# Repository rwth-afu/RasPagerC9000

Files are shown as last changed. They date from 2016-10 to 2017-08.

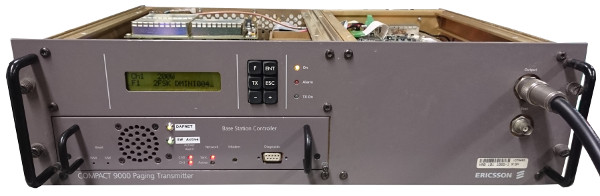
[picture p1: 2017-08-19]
software/website/frontansicht_klein.jpg

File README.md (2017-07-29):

# RasPagerC9000
Adapted Version of RasPager to generate Signals for Ericsson C9000 Paging Transmitter

Authors:
* Ralf Wilke DH3WR, Aachen
* Michael Delissen, Aachen
* Marvin Menzerath, Aachen
* Christian Jansen, Aachen
* Philipp Thiel, Aachen
* Thomas Gatzweiler

This software is released free of charge under the Creative Commons License of type "by-nc-sa". No commercial use is allowed. The software licenses of the used libs apply in any case.

Please notice that there is a new software development without the need of java and with web frontend. Check out https://github.com/rwth-afu/UniPager

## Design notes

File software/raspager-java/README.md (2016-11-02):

# RasPagerC9000: Java

## Run
* Install [Wiring Pi](http://wiringpi.com/download-and-install/)
* Create a configfile (using the example below)
* Run `root@raspberrypi:~# java -jar RasPagerC9000.jar -configfile=config.txt`

### Use Serial Port
You may need to prepeare the serial port interface first. There are two options available:

#### Simple
1. Use `raspi-config` to disable the console on the serial port.
2. Set `enable_uart=1` in `/boot/config.txt`
3. Reboot.

#### Advanced
1. Remove the `console=ttyAMA0,115200` and `kgdboc=ttyAMA0,115200` configuration parameters from the `/boot/cmdline.txt` configuration file.
2. Edit the `/etc/inittab` file and comment out the use of the `ttyAMA0` serial port.
3. Reboot.

## Example-Configuration
```
#[slave config]
# Port
port=1337

# Allowed Masters, separated by a space
master=127.0.0.1

# Baudrate (recommended: 9600, 19200, 38400, 76800)
baudrate=38400

# LogLevel
# NORMAL = 0; DEBUG_CONNECTION = 1; DEBUG_SENDING = 2; DEBUG_TCP = 3;
loglevel=0
```

## Build
* Java JDK 1.8
* Libraries
	* [Pi4J](http://pi4j.com/)
		* `pi4j-core.jar`
		* `pi4j-device.jar`
		* `pi4j-gpio-extension.jar`
		* `pi4j-service.jar`

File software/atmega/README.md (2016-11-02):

# Installing the dependencies

    make install_dependencies

Or manually:

    sudo apt-get install avrdude gcc-avr binutils-avr avr-libc

# Compiling

    make

# Burning the fuses

    make fuses

# Flashing the firmware

    make program

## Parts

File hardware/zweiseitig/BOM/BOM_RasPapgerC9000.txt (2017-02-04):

Comment	Description	Designator	Footprint	Quantity	Value

"ATmega8L-8AC"	"8-Bit AVR Microcontroller with 8K Bytes of In-System Programmable Flash Memory"	"U1"	"32A_N"	"1"	""
"BC847CLT1"	"General Purpose Transistor NPN Silicon"	"Q1, Q2, Q3"	"SOT-23"	"3"	""
"Cap"	"Capacitor"	"C1, C2, C3, C4, C5, C6"	"0805"	"6"	"15pF, 15pF, 100nF, 100nF, 100nF, 100nF"
"Power 5V"	"Header, 2-Pin"	"P4"	"HDR1X2"	"1"	""
"Front_LED"	"Header, 3-Pin"	"P3"	"HDR1X3"	"1"	""
"OneWire"	"Header, 3-Pin"	"P5"	"HDR1X3"	"1"	""
"C9000_Connector"	"Header, 4-Pin"	"P2"	"HDR1X4"	"1"	""
"GPIO RaspberryPi"	"Header, 13-Pin, Dual row"	"P1"	"HDR2X13"	"1"	""
"TOP LED gelb"	""	"D2"	"0805"	"1"	""
"TOP LED grün"	""	"D3"	"0805"	"1"	""
"TOP LED rot"	""	"D1"	"0805"	"1"	""
""	"Resistor"	"R1, R2, R3, R4, R5, R6, R7, R8, R9, R10, R11, R12"	"0805"	"12"	"330, 1k, 1k, 1k, 1k, 1k, 330, 330, 10k, 330, 330, 4k7"
"8 MHz"	"Crystal Oscillator"	"Y1"	"HC49/4H SMX"	"1"	""

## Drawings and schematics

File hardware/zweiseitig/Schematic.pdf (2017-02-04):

## GPIO Interface Raspberry Pi 1

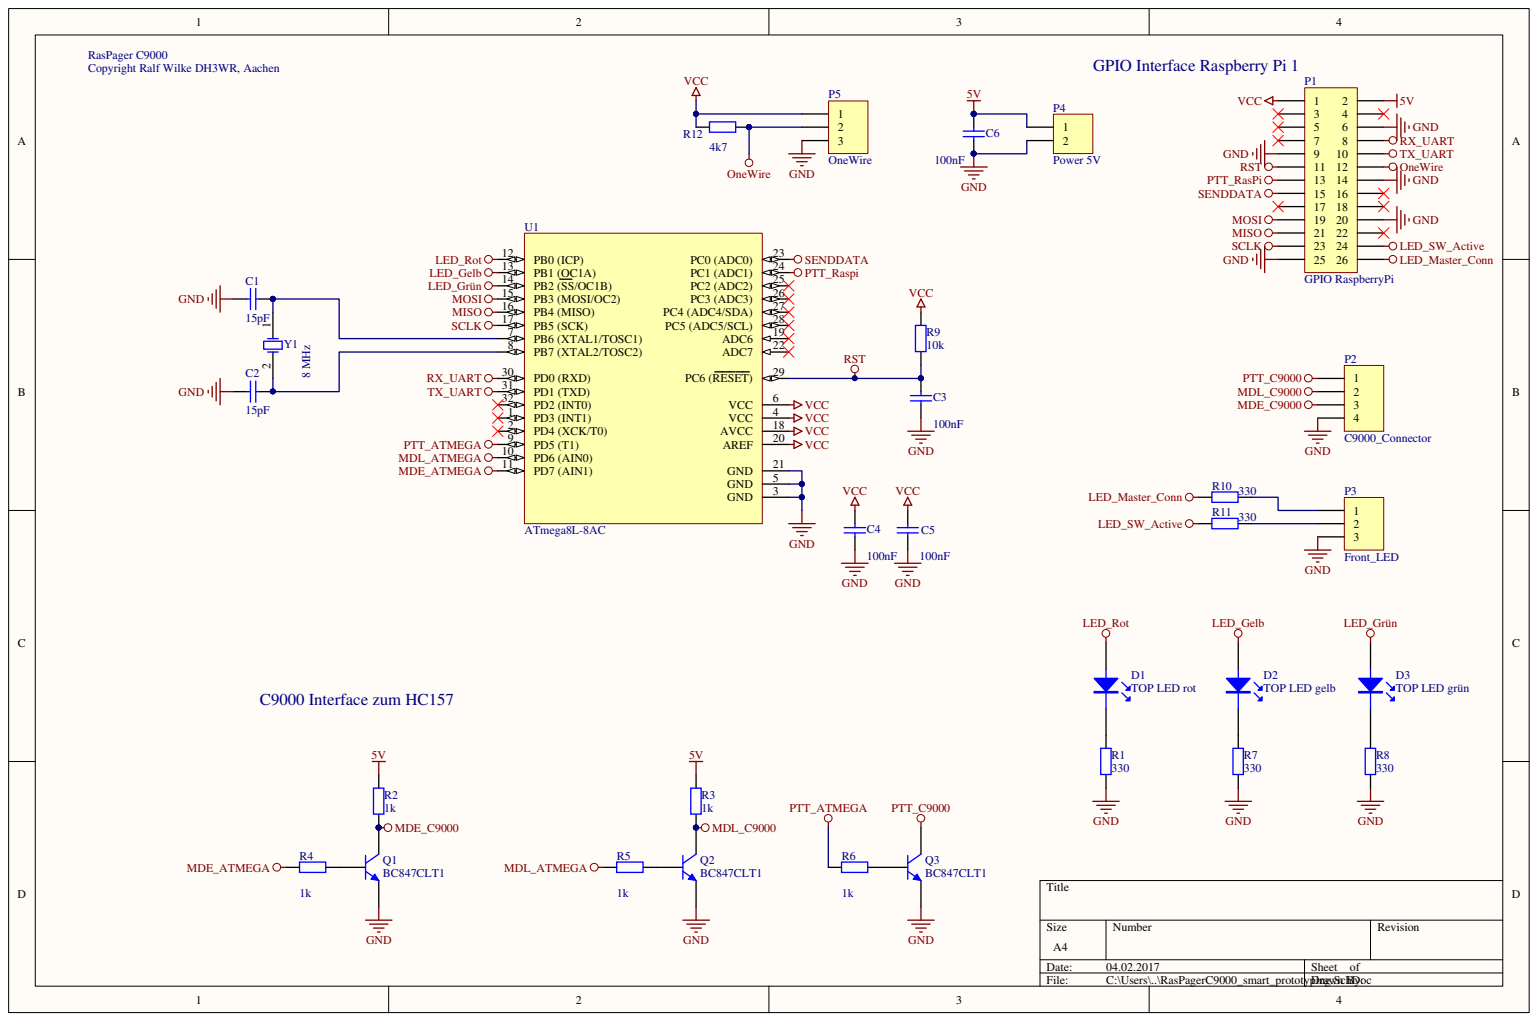
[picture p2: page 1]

RasPager C9000
Copyright Ralf Wilke DH3WR, Aachen

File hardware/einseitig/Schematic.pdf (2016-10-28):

## GPIO Interface Raspberry Pi 1

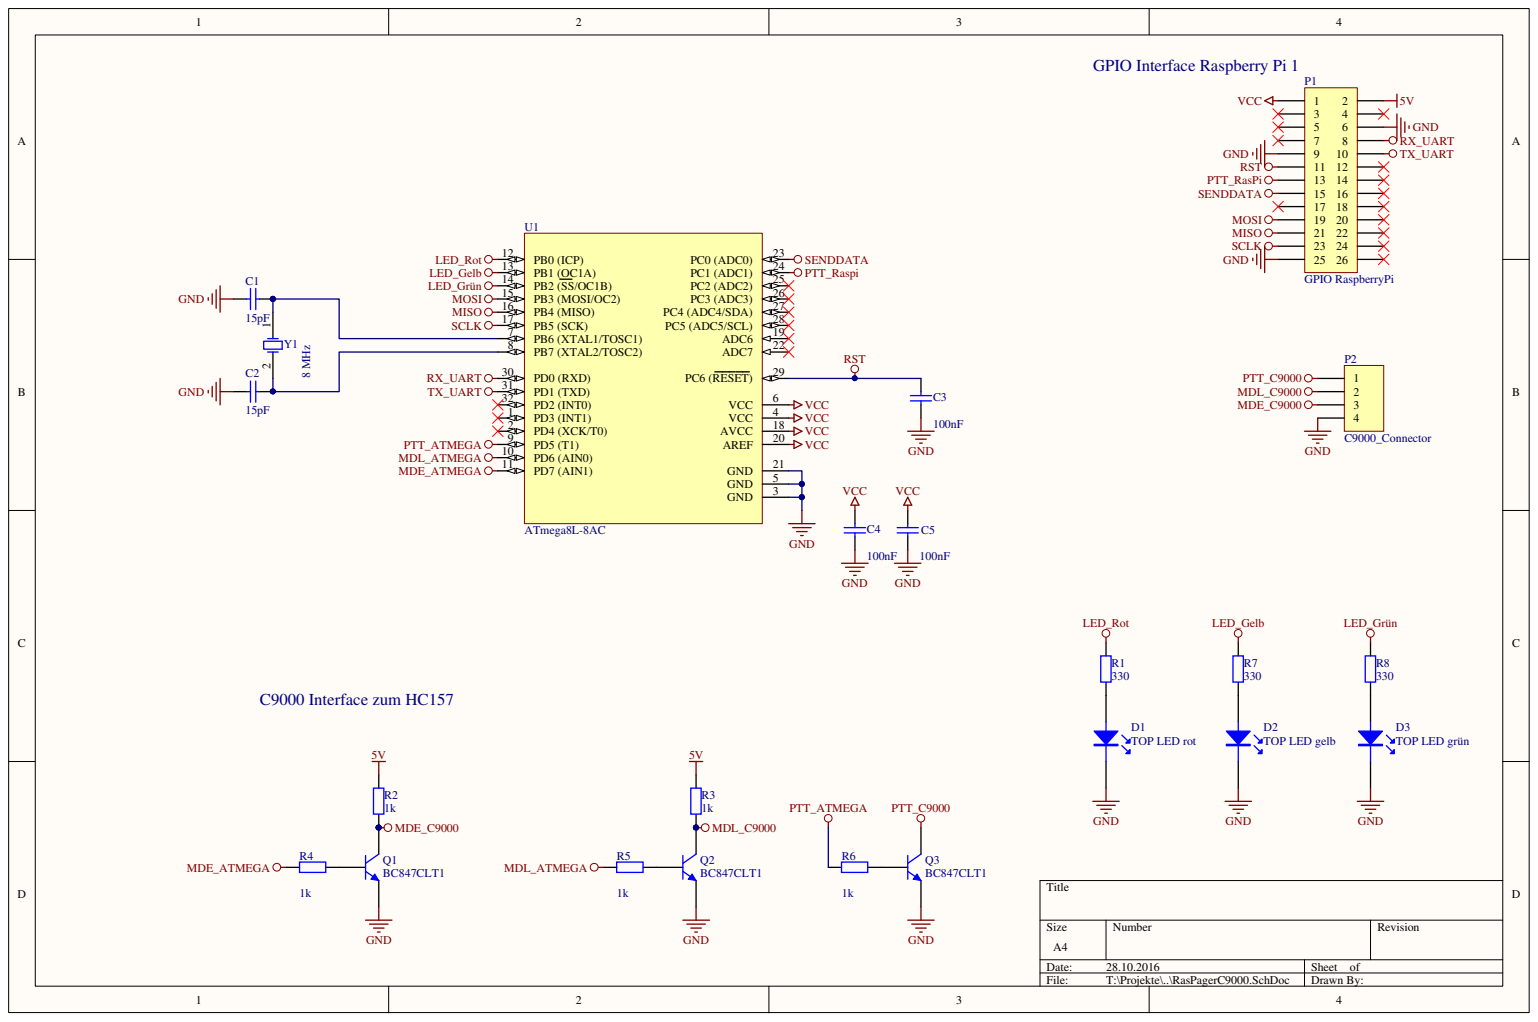
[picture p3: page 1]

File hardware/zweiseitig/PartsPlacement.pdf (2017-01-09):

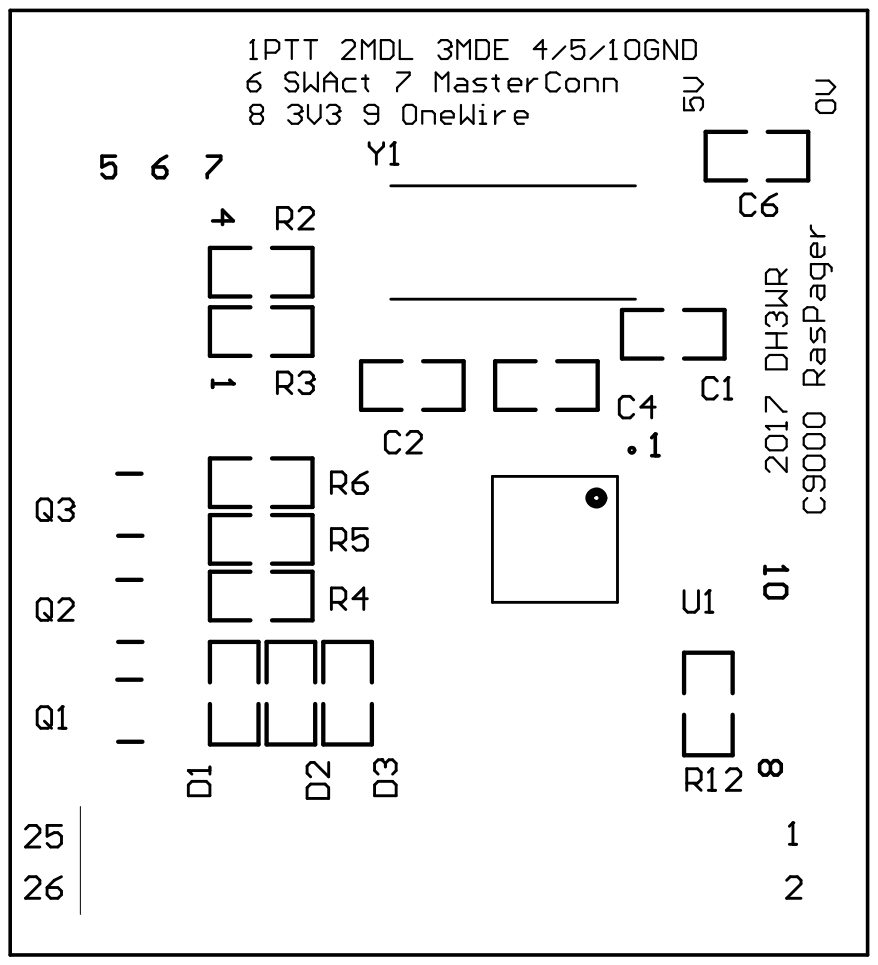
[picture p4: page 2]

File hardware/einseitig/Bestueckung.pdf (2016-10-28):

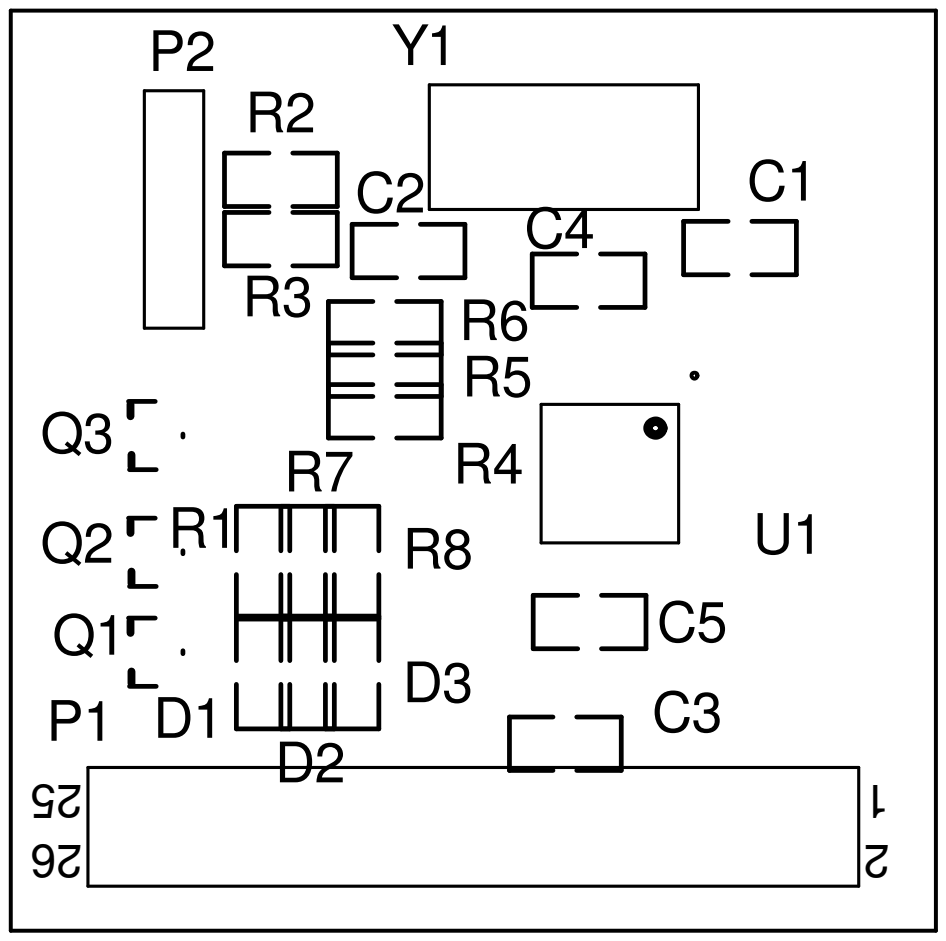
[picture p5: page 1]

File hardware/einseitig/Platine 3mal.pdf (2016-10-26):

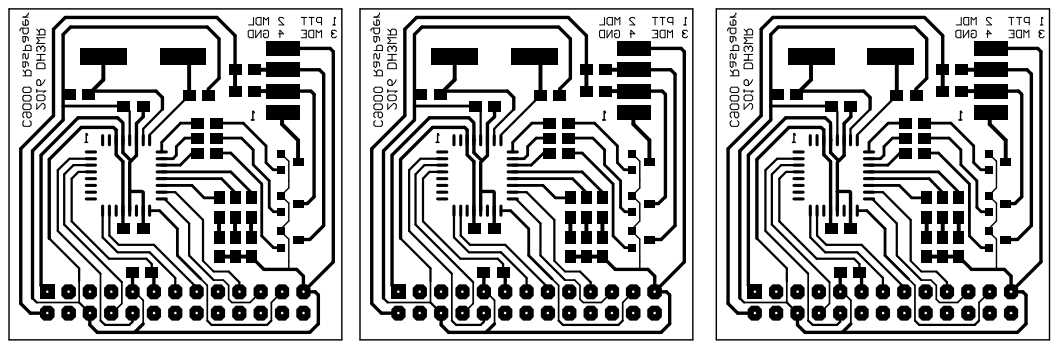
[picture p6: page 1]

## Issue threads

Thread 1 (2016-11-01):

UART Baudrate

7h0ma5, 2016-11-01:
Mit dem 8 MHz-Quarz sind 57600 baud leider nur mit einer Abweichung von 2.1 % möglich. Dazu kommt dann noch die Abweichung des Taktes vom Raspberry Pi, welche sich entweder positiv oder negativ darauf auswirken kann. Ich schlage vor, die Baudrate entweder auf 38400 baud oder auf 76800 baud zu ändern, da die Abweichung dann nur 0.2 % beträgt.

Mögliche Baudraten für f<sub>osc</sub> = 8 MHz:
<table>
  <tr>
    <th></th>
    <th colspan="2">U2X = 0</th>
    <th colspan="2">U2X = 1</th>
  </tr>
  <tr>
    <th>Baudrate</th>
    <th>UBRR</th>
    <th>Error</th>
    <th>UBRR</th>
    <th>Error</th>
  </tr>
  <tr>
    <td>9600</td>
    <td><b>51</b></td>
    <td><b>0.2 %</b></td>
    <td><b>103</b></td>
    <td><b>0.2 %</b></td>
  </tr>
  <tr>
    <td>14400</td>
    <td>34</td>
    <td>-0.8 %</td>
    <td>68</td>
    <td>0.6 %</td>
  </tr>
  <tr>
    <td>19200</td>
    <td><b>25</b></td>
    <td><b>0.2 %</b></td>
    <td><b>51</b></td>
    <td><b>0.2 %</b></td>
  </tr>
  <tr>
    <td>28800</td>
    <td>16</td>
    <td>2.1 %</td>
    <td>34</td>
    <td>-0.8 %</td>
  </tr>
  <tr>
    <td>38400</td>
    <td><b>12</b></td>
    <td><b>0.2 %</b></td>
    <td><b>25</b></td>
    <td><b>0.2 %</b></td>
  </tr>
  <tr>
    <td>57600</td>
    <td>8</td>
    <td>-3.5 %</td>
    <td>16</td>
    <td>2.1 %</td>
  </tr>
  <tr>
    <td>76800</td>
    <td>6</td>
    <td>-7.0 %</td>
    <td><b>12</b></td>
    <td><b>0.2 %</b></td>
  </tr>
  <tr>
    <td>115200</td>
    <td>3</td>
    <td>8.5 %</td>
    <td>8</td>
    <td>-3.5 %</td>
  </tr>
</table>

dh3wr, 2016-11-02:
OK, wir nehmen dann 76800 Baud.
Marvin, bitte ebenfalls in der Java-Software ändern.
Thomas, hast du es geschafft den AVR zur programmieren?

dh3wr, 2016-11-02:
Nach Absprache mit Marvin wird die Baudrate ein Config-Parameter im Configfile. 76k8 sind unter Umständen mit der Java-Lib nicht möglich. Die möglichen Baudraten werden im Configfile als Kommentar aufgeführt.

7h0ma5, 2016-11-02:
In der config.h-Datei gibt es jetzt auch die Option, die Baudrate einzustellen, standardmäßig ist momentan 38400 eingestellt.

@dh3wr Das Programmieren des AVR hat ohne Probleme funktioniert, die Software ist auch schon fertig und muss nur noch am C9000 getestet werden, mit dem Oszilloskop sieht aber alles schon gut aus. Da am Reset-Pin des AVR kein Pull-Up-Widerstand vorhanden ist, muss den GPIO0 bzw. Pin 11 des Headers auf High setzten, damit der AVR startet. Zum einfachen Testen habe ich dafür die Targets "start" und "stop" im Makefile eingefügt. Wie man die Firmware flasht steht im Readme im "software/atmega"-Verzeichnis.

dh3wr, 2016-11-02:
@7h0ma5 : Sehr schön, dann werde ich für morgen einen C9000 zum Testen mal vorbereiten. Die Fkt. der gelben LED hatte ich als "Es sind noch Daten im Buffer zum Aussenden drin". Ist das so programmiert?

Es kann noch sein, dass der Ausgang des POCSAG invertiert werden muss. Kann man das noch in der config.h einbauen?

MarvinMenzerath, 2016-11-02:
> Da am Reset-Pin des AVR kein Pull-Up-Widerstand vorhanden ist, muss man den GPIO0 bzw. Pin 11 des Headers auf High setzten, damit der AVR startet.

@7h0ma5 Soll sich da die Java-Anwendung drum kümmern?

7h0ma5, 2016-11-02:
@dh3wr Momentan zeigt die grüne LED an, dass der AVR läuft, die rote LED, dass PTT aktiv ist und die gelbe LED, ob gerade eine 1 oder 0 gesendet wird, so wie die RX/TX LEDs bei einem Arduino. Ich kann das aber gerne ändern.

@MarvinMenzerath Ja, das wäre am einfachsten. Ich hatte das auch schon als Kommentar zu einem Commit geschrieben, eigentlich müsste GitHub dann eine Benachrichtigung verschicken: https://github.com/rwth-afu/RasPagerC9000/commit/afc333ca16bf2674587427343b46328bf42fc67b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

MarvinMenzerath, 2016-11-02:
Oh, dann hab ich das wohl übersehen...
Die Änderung ist jetzt in Commit 5738b1af648758c43531df412ecd4444987289ab und in der [neuen JAR](https://github.com/rwth-afu/RasPagerC9000/blob/master/software/raspager-java/bin/2016-11-02_15-33_RasPagerC9000.jar) enthalten.

7h0ma5, 2016-11-02:
@dh3wr Mit dem Commit 69eaeebadf20d84ec1042e806df4037292dbc06c kann man jetzt in der config.h über die Option INVERT_BITS das Invertieren der Bits aktivieren.

Closed 2016-11-02.

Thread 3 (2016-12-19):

Bit Timing ist unterschiedlich zwischen SDRPager und C9000 Pager

dh3wr, 2016-12-19:
Wenn man mit beiden eine Aussendung des gleichen Inhalts macht, dann geht es mit dem DH3WR Skyper mit dem SDRPager und mit dem C9000 nicht.
Ein Vergleich des Audio-Daten zeigt bei Ausrichtung am Übergang Präambel->Anfang
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

Am Ende sind die Daten aber deutlich verschoben
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

Es muss noch herausgefunden werden, welche Variante jetzt richtig ist.

dh3wr, 2016-12-19:
Ich habe mal die Timerwerte angeschaut und etwas verändert. Morgen mal testen. Siehe Commit 3b7001c4100b7289c22ec4d4a0dbcae68595bd90

dh3wr, 2016-12-20:
Hmm, die Änderung hat den Versatz noch schlechter gemacht und nun ist auch kein Empfang mit dem DB6AC Skyper mehr möglich. Weitere Untersuchung notwendig.

dh3wr, 2016-12-20:
@7h0ma5 Spricht etwas dagegen, einen 16 Bit Timer zu nehmen, um den Unterschied zwischen der "krummen Rate" von 1200 Baud und dem 8 MHz Clock zu haben? Mit 16 Bit und einem entsprechenden Prescaler sollte sich die Auflösung doch verbessern lassen, oder?

dh3wr, 2016-12-20:
Nun, der RasPi commited zwar mit Thomas Identität, aber egal. Problem mit Commit 66040d1d9ba4988e30cfa8db10f434359954c17c gelößt. Timer 1 erzeugt nun mit reload-Wert 6666 -> 1199.94 Hz . Das ist schon deutlich näher dran als mit dem 8 Bit Timer2.

7h0ma5, 2016-12-20:
Ich hatte leider gerade erst Zeit mir das anzusehen. Die Lösung mit dem 16-Bit-Timer ist auf jedenfall wesentlich besser. Die Initialisierung des 8-Bit-Timers hatte ich aus dem Quellcode für den ATmega des Raspagers kopiert:

Closed 2016-12-20.

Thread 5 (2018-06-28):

AVR not responding

tokio69, 2018-06-28:
Hello,
should this work also with a blank ATMega?
I have some fresh ones that have never been programmed before cause I don't have a programmer.
I followed the wiki and on the "make fuses" command I get this error :

_pi@raspberrypi:~/RasPagerC9000/software/atmega $ make fuses
sudo avrdude -C +./avrdude.conf -c raspberry_pi -p m8 -U lfuse:w:0xff:m -U hfuse:w:0xc9:m

avrdude: AVR device not responding
avrdude: initialization failed, rc=-1
         Double check connections and try again, or use -F to override
         this check.

avrdude done.  Thank you.

Makefile:38: recipe for target 'fuses' failed
make: *** [fuses] Error 1_

dh3wr, 2018-06-29:
Hi Tom,
Yes it should work. Try first ``make program`` and afterwards ``make fuses``

dh3wr, 2018-06-29:
If you still get the error, there is a wiring problem (not all ISP connections to ATMega ok?) Or some other service is accessing and thus blocking the GPIO-Lines.

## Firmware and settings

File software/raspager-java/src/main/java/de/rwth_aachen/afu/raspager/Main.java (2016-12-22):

package de.rwth_aachen.afu.raspager;

import java.io.FileNotFoundException;
import java.io.IOException;
import java.io.OutputStream;
import java.io.PrintStream;
import java.util.logging.Level;
import java.util.logging.Logger;

import org.apache.commons.cli.CommandLine;
import org.apache.commons.cli.CommandLineParser;
import org.apache.commons.cli.DefaultParser;
import org.apache.commons.cli.HelpFormatter;
import org.apache.commons.cli.Options;
import org.apache.commons.cli.ParseException;

public final class Main {
	private static final Logger log = Logger.getLogger(Main.class.getName());
	private static boolean startService = false;
	private static boolean withTrayIcon = true;

	private static void initRxTx() {
		// Preventing rxtx to write to the console
		PrintStream out = System.out;
		System.setOut(new PrintStream(new OutputStream() {
			@Override
			public void write(int b) throws IOException {
			}
		}));

		try {
			Class.forName("gnu.io.RXTXCommDriver");
		} catch (ClassNotFoundException e) {
			log.log(Level.SEVERE, "Failed to load RXTX.", e);
		} finally {
			System.setOut(out);
		}
	}

	private static void printVersion() {
		System.out.println("RasPagerC9000 - Version 1.0.0");
		System.out.println("by Ralf Wilke, Michael Delissen, Marvin Menzerath, Thomas Gatzweiler and Phillip Thiel, powered by IHF RWTH Aachen");
		System.out.println("New Versions at https://github.com/rwth-afu/RasPagerC9000/releases");
		System.out.println();
	}

	private static boolean parseArguments(String[] args, Configuration config) {
		Options opts = new Options();
		opts.addOption("c", "config", true, "Configuration file to use.");
		opts.addOption("h", "help", false, "Show this help.");
		opts.addOption("v", "version", false, "Show version information.");
		opts.addOption("s", "service", false, "Run as a service without a GUI.");
		opts.addOption("notrayicon", false, "Disable tray icon.");

		CommandLineParser parser = new DefaultParser();
		CommandLine line = null;
		try {
			line = parser.parse(opts, args);
		} catch (ParseException ex) {
			log.log(Level.SEVERE, "Failed to parse command line.", ex);
			return false;
		}

		if (line.hasOption('h')) {
			HelpFormatter fmt = new HelpFormatter();
			fmt.printHelp("raspager-sdr", opts);
			return false;
		}

		if (line.hasOption('v')) {
			printVersion();
			return false;
		}

		if (line.hasOption('s')) {
			startService = true;
		}

		if (line.hasOption("notrayicon")) {
			withTrayIcon = false;
		}

		try {
			String configFile = line.getOptionValue('c', "raspager.properties");
			config.load(configFile);
		} catch (FileNotFoundException ex) {
			log.log(Level.WARNING, "Failed to load configuration: {0}", ex.getMessage());
		} catch (Throwable t) {
			log.log(Level.SEVERE, "Failed to load configuration.", t);
		}

		return true;
	}

	public static void main(String[] args) {
		Thread.setDefaultUncaughtExceptionHandler((t, e) -> {
			log.log(Level.SEVERE, String.format("Uncaught exception in thread %s.", t.getName()), e);
		});

		Configuration config = new Configuration();
		if (!parseArguments(args, config)) {
			return;
		}

		initRxTx();

		RasPagerService app = null;
		try {
			app = new RasPagerService(config, startService, withTrayIcon);
			app.run();
		} catch (Throwable t) {
			log.log(Level.SEVERE, "Main application error.", t);
		} finally {
			if (app != null) {
				app.shutdown();
			}
		}
	}
}

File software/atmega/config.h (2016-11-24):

#pragma once

// CPU Frequency
#define F_CPU 8000000

// Recommended values: 9600, 19200, 38400, 76800
#define UART_BAUDRATE 38400

// Invert each bit before transmitting
#define INVERT_BITS true

// LED_RED -> This pin drives the red LED
#define LED_RED_DDR         DDRB
#define LED_RED_PORT        PORTB
#define LED_RED_PIN         PINB
#define LED_RED_BIT         PINB0

// LED_YELLOW -> This pin drives the yellow LED
#define LED_YELLOW_DDR      DDRB
#define LED_YELLOW_PORT     PORTB
#define LED_YELLOW_PIN      PINB
#define LED_YELLOW_BIT      PINB1

// LED_GREEN -> This pin drives the green LED
#define LED_GREEN_DDR       DDRB
#define LED_GREEN_PORT      PORTB
#define LED_GREEN_PIN       PINB
#define LED_GREEN_BIT       PINB2

// C9000_PTT -> This pin drives the PTT line of C9000, High means C9000 is set to Ground = Low
#define C9000_PTT_DDR       DDRD
#define C9000_PTT_PORT      PORTD
#define C9000_PTT_PIN       PIND
#define C9000_PTT_BIT       PIND5

// C9000_MDL -> This pin drives the MDL line of C9000, High means C9000 MDL is set to Ground = Low
#define C9000_MDL_DDR       DDRD
#define C9000_MDL_PORT      PORTD
#define C9000_MDL_PIN       PIND
#define C9000_MDL_BIT       PIND6

// C9000_MDE -> This pin drives the MDE line of C9000, High means C9000 MDE is set to Ground = Low
#define C9000_MDE_DDR       DDRD
#define C9000_MDE_PORT      PORTD
#define C9000_MDE_PIN       PIND
#define C9000_MDE_BIT       PIND7

// RASPI_SENDATA -> This pin signals the Raspberry Pi that data can be received
#define RASPI_SENDDATA_DDR  DDRC
#define RASPI_SENDDATA_PORT PORTC
#define RASPI_SENDDATA_PIN  PINC
#define RASPI_SENDDATA_BIT  PINC0

// RASPI_PTT -> This pin goes to High if the Raspberry Pi wants to send data
#define RASPI_PTT_DDR       DDRC
#define RASPI_PTT_PORT      PORTC
#define RASPI_PTT_PIN       PINC
#define RASPI_PTT_BIT       PINC1

// Bit Manipulation
#define SET_BIT(var, bitnum)   (var) |=  (1 << (bitnum))
#define CLR_BIT(var, bitnum)   (var) &= ~(1 << (bitnum))
#define TGL_BIT(var, bitnum)   (var) ^=  (1 << (bitnum))
#define GET_BIT(var, bitnum)   (((var) >> (bitnum)) & 0x1)

// IO Defines
#define INIT_OUTPUT(signal)  {SET_BIT(signal##_DDR,  signal##_BIT);}
#define SET_OUTPUT(signal)   {SET_BIT(signal##_PORT, signal##_BIT);}
#define CLR_OUTPUT(signal)   {CLR_BIT(signal##_PORT, signal##_BIT);}
#define TGL_OUTPUT(signal)   {TGL_BIT(signal##_PORT, signal##_BIT);}
#define GET_INPUT(signal)    (GET_BIT(signal##_PIN,  signal##_BIT))

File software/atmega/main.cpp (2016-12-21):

#include "config.h"
#include <avr/io.h>
#include <avr/interrupt.h>
#include <util/delay.h>
#include <stdint.h>

#include "uart.h"
#include "fifo.h"

extern void panic();

Fifo<uint8_t> fifo = Fifo<uint8_t>(256);
static bool reception_ok = true;

void timer_init() {
/*  // Initialize timer for 1200 Hz
  TCCR2 = (1 << WGM21) | (1 << CS22);
  OCR2  = F_CPU / 64 / 1207;
  TIMSK = (1 << OCIE2) | (1 << TOIE2);
*/
  // Initialize timer 1 for 1200 Hz
  // No Output on compare match, no PWM
  TCCR1A = 0x00;
  // Clear Timer on match, CPU-Clock as input
  TCCR1B = (1 << WGM12) | (1 << CS10);
  OCR1A = 6666;
  TIMSK = (1 << OCIE1A);
}

void ports_init() {
  INIT_OUTPUT(LED_RED);
  CLR_OUTPUT(LED_RED);

  INIT_OUTPUT(LED_YELLOW);
  CLR_OUTPUT(LED_YELLOW);

  INIT_OUTPUT(LED_GREEN);
  SET_OUTPUT(LED_GREEN);

  INIT_OUTPUT(C9000_MDL);
  SET_OUTPUT(C9000_MDL);

  INIT_OUTPUT(C9000_MDE);
  CLR_OUTPUT(C9000_MDE);

  INIT_OUTPUT(C9000_PTT);
  CLR_OUTPUT(C9000_PTT);

  INIT_OUTPUT(RASPI_SENDDATA);
  SET_OUTPUT(RASPI_SENDDATA);
}

/**
 * Main loop
 */
void loop() {
  uint16_t free_slots = fifo.getFreeSlots();
  uint16_t count = fifo.getCount();

  // Stop receiving if the buffer is full
  if (!free_slots) {
    CLR_OUTPUT(RASPI_SENDDATA);
    panic();
  }
  else {
	if (reception_ok) {
		uint8_t received_byte = UART::receive_byte();
		fifo.push(received_byte);
		count = fifo.getCount();
		
		if (count >= 125) {
			// Signal the PI to stop sending data if the buffer gets close to full
			CLR_OUTPUT(RASPI_SENDDATA);
		}
		if (count >= 160) {
			reception_ok = false;
		}
    }
  }
}

/**
 * 1200 Hz timer interrupt
 */
ISR(TIMER1_COMPA_vect) {
  static uint8_t current_byte = 0;
  static uint8_t remaining_bits = 0;

  bool fifo_empty = fifo.isEmpty();

  // Set PTT to High if there is data left
  // or the Raspberry Pi wants to send
  if (remaining_bits || !fifo_empty || GET_INPUT(RASPI_PTT)) {
    SET_OUTPUT(LED_RED);
    SET_OUTPUT(C9000_PTT);
  }
  else {
    CLR_OUTPUT(LED_RED);
    CLR_OUTPUT(C9000_PTT);
  }

  if (remaining_bits == 0 && !fifo_empty) {
    current_byte = fifo.pop();
    remaining_bits = 8;
  }

  if (remaining_bits > 0) {
    uint8_t bit = current_byte & (1 << (remaining_bits - 1));

    if ((!INVERT_BITS && bit) || (INVERT_BITS && !bit)) {
      CLR_OUTPUT(C9000_MDL);
      SET_OUTPUT(LED_YELLOW);
    } else {
      SET_OUTPUT(C9000_MDL);
      CLR_OUTPUT(LED_YELLOW);
    }

    for (int i = 0; i < 8; i++) asm volatile("nop");
    SET_OUTPUT(C9000_MDE);
    for (int i = 0; i < 8; i++) asm volatile("nop");
    CLR_OUTPUT(C9000_MDE);

    remaining_bits--;
  }
  else {
    SET_OUTPUT(C9000_MDL);
    CLR_OUTPUT(LED_YELLOW);
  }
  // Check if we have to enable the reception again
  uint16_t count = fifo.getCount();
  if (count <= 70) {
	// if it the count is 120 or below, enable reception again
	reception_ok = true;
	SET_OUTPUT(RASPI_SENDDATA);
  }
}

int main() {
  ports_init();
  timer_init();
  UART::init();
  sei();

  while (1) { loop(); }
  return 0;
}

void panic() {
  INIT_OUTPUT(LED_RED);
  INIT_OUTPUT(LED_YELLOW);
  INIT_OUTPUT(LED_GREEN);

  for (int i = 0; i < 100; i++) {
    SET_OUTPUT(LED_RED);
    SET_OUTPUT(LED_YELLOW);
    SET_OUTPUT(LED_GREEN);
    _delay_ms(50);
    CLR_OUTPUT(LED_RED);
    CLR_OUTPUT(LED_YELLOW);
    CLR_OUTPUT(LED_GREEN);
    _delay_ms(50);
  }
}

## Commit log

2016-10-19 Initial commit of hardware
    [RasPagerC9000.PcbDoc, RasPagerC9000.PrjPcb, RasPagerC9000.SchDoc]
2016-10-26 Wider pads for GPIO header
    [RasPagerC9000.PcbDoc, RasPagerC9000.PrjPcb, RasPagerC9000.SchDoc]
2016-10-26 Added PCB printout
2016-10-28 Changed XTAL Frequency from 12 MHz to 8 MHz, added part placement drawing
    [RasPagerC9000.PcbDoc, RasPagerC9000.SchDoc]
2016-11-01 Implement C9000 MDE signal and status LED outputs
2016-11-02 Add the option to invert data bits to config.h
    [config.h, main.cpp]
2016-11-02 Improve thread-safety of Fifo class
2016-11-03 Set MDL pin to LOW as default
2016-11-11 Bugfixing on ATMega Software, now transfer is running as expected and terminating always. Still no RX on Skypers.
    [config.h, main.cpp]
2016-11-25 Added alarm flashing if an error has happend
    [main.cpp]
2016-11-25 Make writes to FIFO head/tail indices threadsafe
2016-12-19 Code now running, at least with DB6AC Pager, DH3WR & DL5FMK still not working
    [C9000Transmitter.java, Main.java]
2016-12-19 Interrupt freq. of bit output maybe not precise enough, let's try
2016-12-20 Use Timer 1 to generate 1200 Baud Interrupt, now working fine
2016-12-20 Debugged maxBatch calculation, added better state machine handling of non-complete slots.
2016-12-20 Added debug message for max Batches, added differentiation, if slot is complete or not
2016-12-20 Bug Fix: If slot is incomplete but there is not enough time left for even the preamble, dont's encode
2016-12-20 Forgotten modulo operator at "time left in this slot"-calculation
2016-12-21 Es gibt schon einen Unterschied zwischen a%b und floor(a/b)...
2016-12-21 Syntax error, still not working well with longer calls
    [main.cpp]
2016-12-21 Logic bugfixing with new data transfer method between Pi and ATMega
    [C9000Transmitter.java, main.cpp]
2017-01-09 Added two side version with one wire-Bus connection
    [RasPagerC9000.PcbDoc, RasPagerC9000.PrjPcb, RasPagerC9000.SchDoc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]
2017-01-09 Added schematic and parts placement info
    [RasPagerC9000_smart_prototyping.GBL, RasPagerC9000_smart_prototyping.GBO, RasPagerC9000_smart_prototyping.GBP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]
2017-02-04 Added BOM
    [BOM_RasPapgerC9000.csv, BOM_RasPapgerC9000.xls]
2017-02-04 Updating Schematic with author information
    [RasPagerC9000_smart_prototyping.PcbDoc, RasPagerC9000_smart_prototyping.PrjPcb, RasPagerC9000_smart_prototyping.SchDoc]
2017-02-04 Refactoring of Excel BOM
    [BOM_RasPapgerC9000.xls]
2017-02-04 Updated BOM with component values that were missing before
    [BOM_RasPapgerC9000.csv, BOM_RasPapgerC9000.xls, RasPagerC9000_smart_prototyping.PrjPcb]
2025-07-24 Add gitignore for KiCad 9
2025-07-24 Exclude KiCad board production files in gitignore
    This allows commiting the BOM and positions csv files.
2025-07-24 Add KiCad project & schematic
    The schematic is electrically identical to the original one.
2025-07-24 Add KiCad PCB layout
2025-07-24 Add KiCad schematic PDF
2025-07-24 Add JLCPCB production files for KiCad hardware
    RasPagerC9000_v2.0.0.zip contains the gerber files.
    The archive, bom and positions file can be uploaded directly to JLCPCB.
2025-07-24 KiCad hw: Add readme including PCB rendering
2025-07-24 KiCad HW: Add warning to readme about untested board
